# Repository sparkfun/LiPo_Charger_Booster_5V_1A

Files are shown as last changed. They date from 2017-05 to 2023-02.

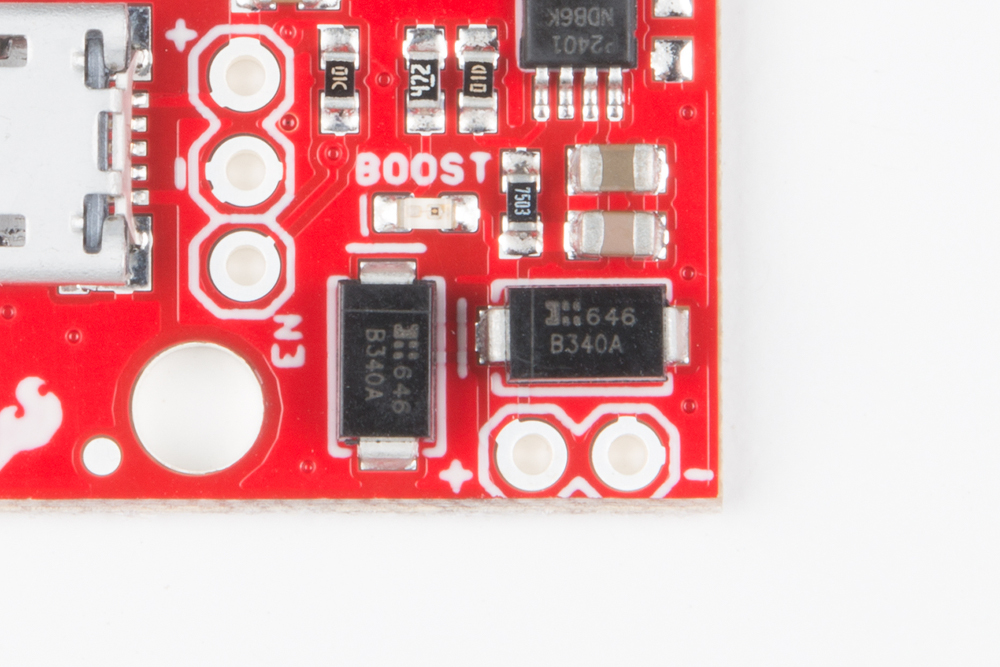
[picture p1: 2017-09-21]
Documentation/Hookup Photos/outputterms.jpg

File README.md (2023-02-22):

SparkFun LiPo Charger/Booster - 5V/1A
========================================

SparkFun LiPo Charger/Booster - 5V/1A (https://www.sparkfun.com/products/14411)

[*SparkFun LiPo Charger/Booster - 5V/1A (PRT-14411)*](https://www.sparkfun.com/products/14411)

The SparkFun 5V/1A LiPo Charger/Booster is a no-nonsense circuit for generating one amp from a Lithium Polymer battery at 5V.

Repository Contents
-------------------

* **/Documentation** - Data sheets, additional product information
* **/Hardware** - Eagle design files (.brd, .sch)
* **/Production** - Production panel files (.brd)

Documentation
--------------
* **[SparkFun Fritzing Part](https://github.com/sparkfun/Fritzing_Parts/blob/main/products/14411_sfe_LiPo_Charger_Booster-5V1A.fzpz)** - Fritzing diagrams for SparkFun products.
* **[Hookup Guide](https://learn.sparkfun.com/tutorials/sparkfun-5v1a-lipo-chargerbooster-hookup-guide)** - Basic hookup guide for the SparkFun LiPo Charger/Booster - 5V/1A.

Product Versions
----------------
* [PRT-14411](https://www.sparkfun.com/products/14411)- LiPo Charger/Booster 5V/1A

Version History
----------------
* [HW-V1.0](https://github.com/sparkfun/LiPo_Charger_Booster_5V_1A/releases/tag/HW-V1.0) 

License Information
-------------------

This product is _**open source**_! 

Please review the LICENSE.md file for license information. 

If you have any questions or concerns on licensing, please contact techsupport@sparkfun.com.

Distributed as-is; no warranty is given.

- Your friends at SparkFun.

_<COLLABORATION CREDIT>_

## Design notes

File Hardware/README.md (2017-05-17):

SparkFun <PRODUCT NAME> Design Files
=====================================

The .sch and .brd files hare are Eagle CAD schematic and PCB design files from SparkFun Electronics.
A freeware version of Eagle can be found [here](http://www.cadsoftusa.com/download-eagle/freeware/).

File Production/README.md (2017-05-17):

SparkFun <PRODUCT NAME> Production Files
=========================================

These are the production files SparkFun uses for printing PCBs.

License Information
-------------------
This product is open source! 

The hardware is released under [Creative Commons ShareAlike 4.0 International](https://creativecommons.org/licenses/by-sa/4.0/).

Please use, reuse, and modify these files as you see fit. Please maintain attribution to SparkFun Electronics and release anything derivative under the same license.

Distributed as-is; no warranty is given.

- Your friends at SparkFun.

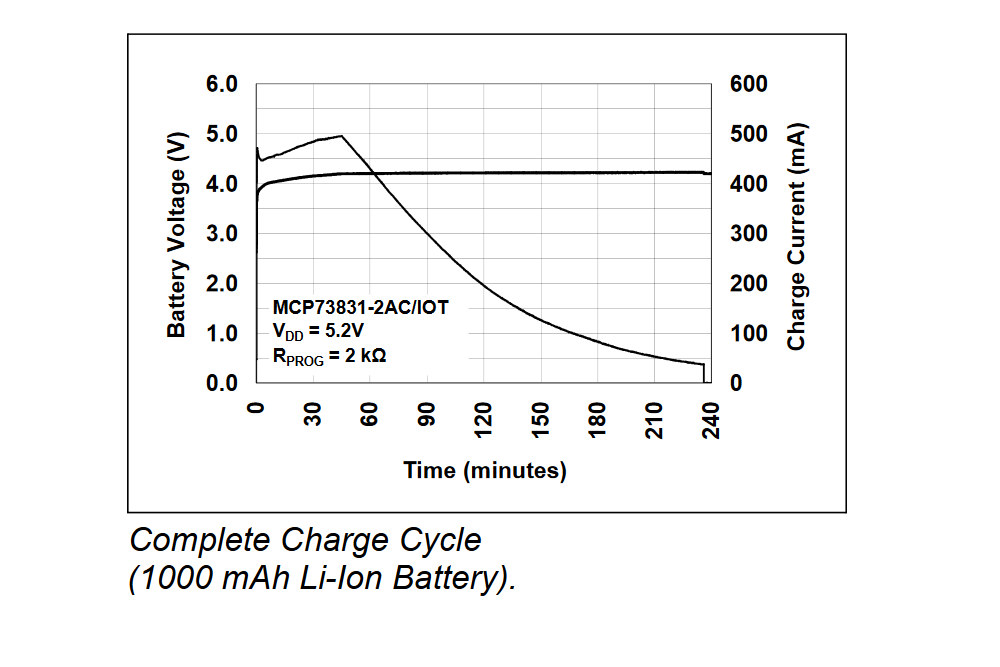
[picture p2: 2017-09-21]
Documentation/Hookup Photos/chargecycle.png

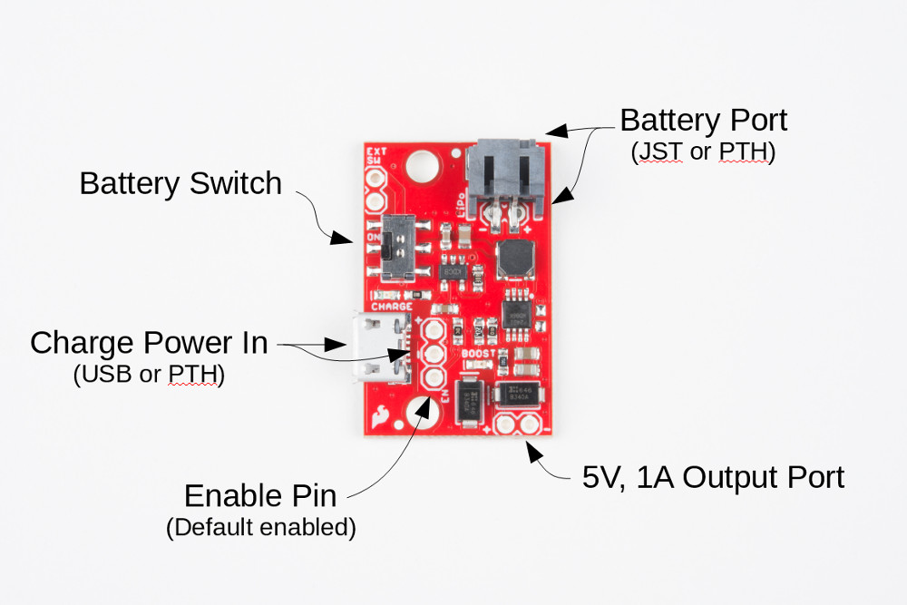
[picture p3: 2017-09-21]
Documentation/Hookup Photos/topside_notated.jpg

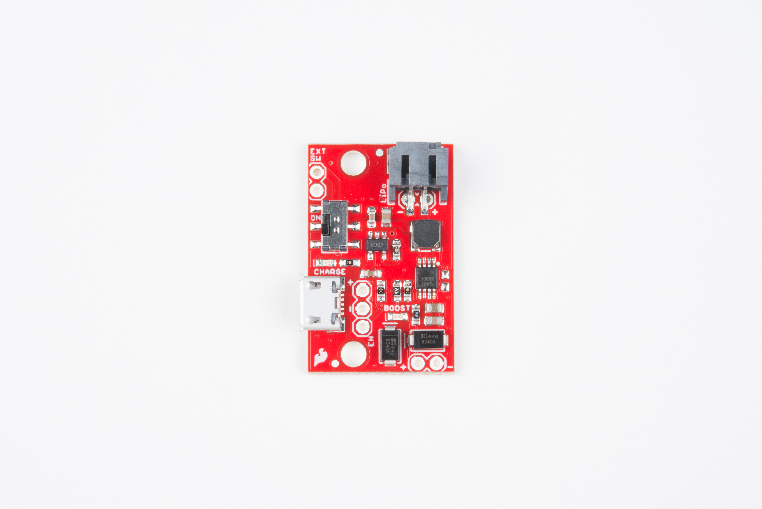
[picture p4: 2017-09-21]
Documentation/Hookup Photos/topside.jpg

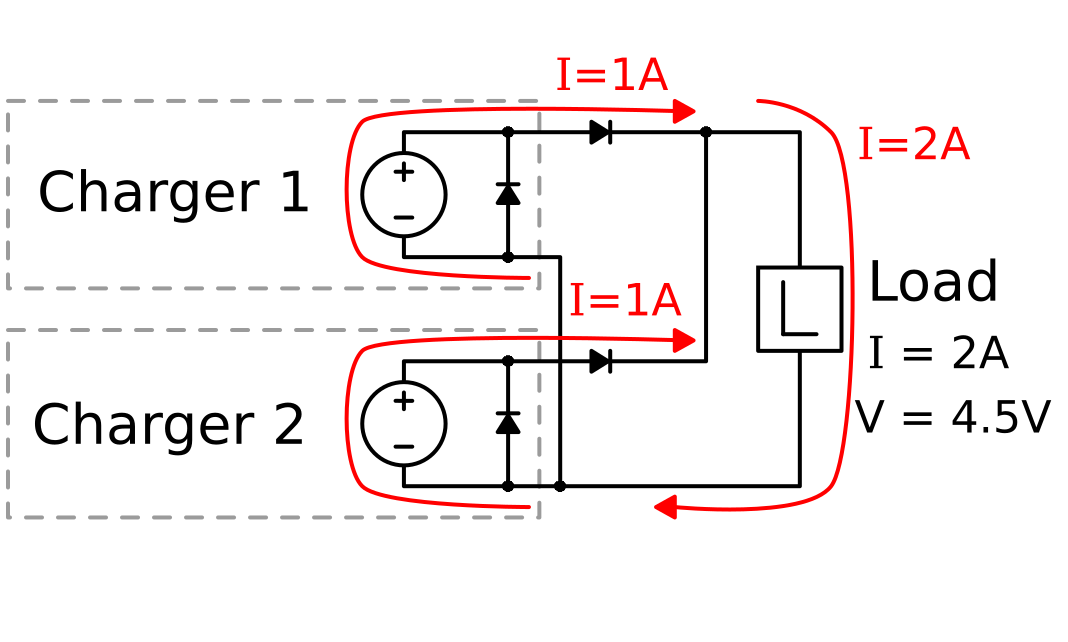
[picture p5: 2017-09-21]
Documentation/Hookup Photos/summingCurrent.png

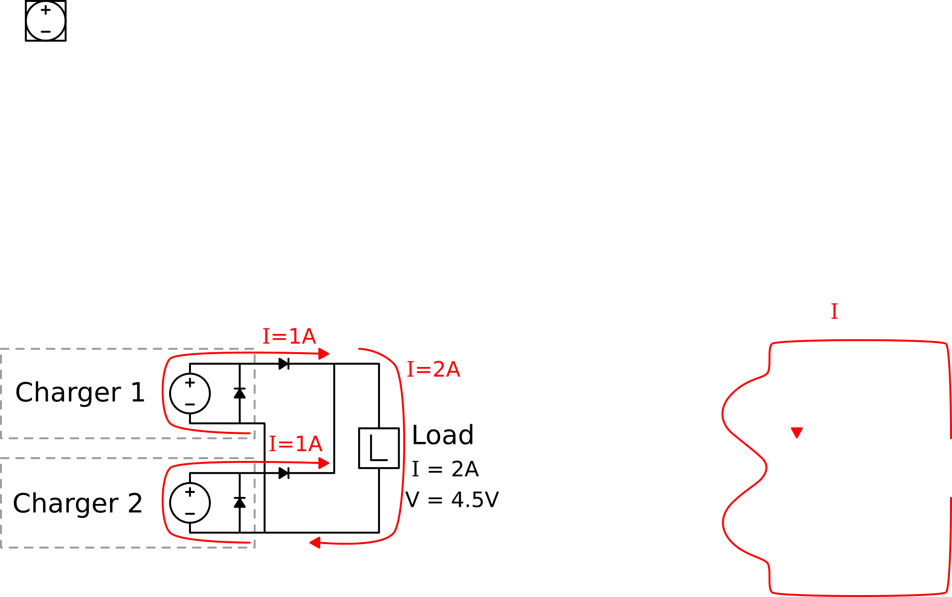
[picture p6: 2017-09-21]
Documentation/Hookup Photos/currentDrawing.png

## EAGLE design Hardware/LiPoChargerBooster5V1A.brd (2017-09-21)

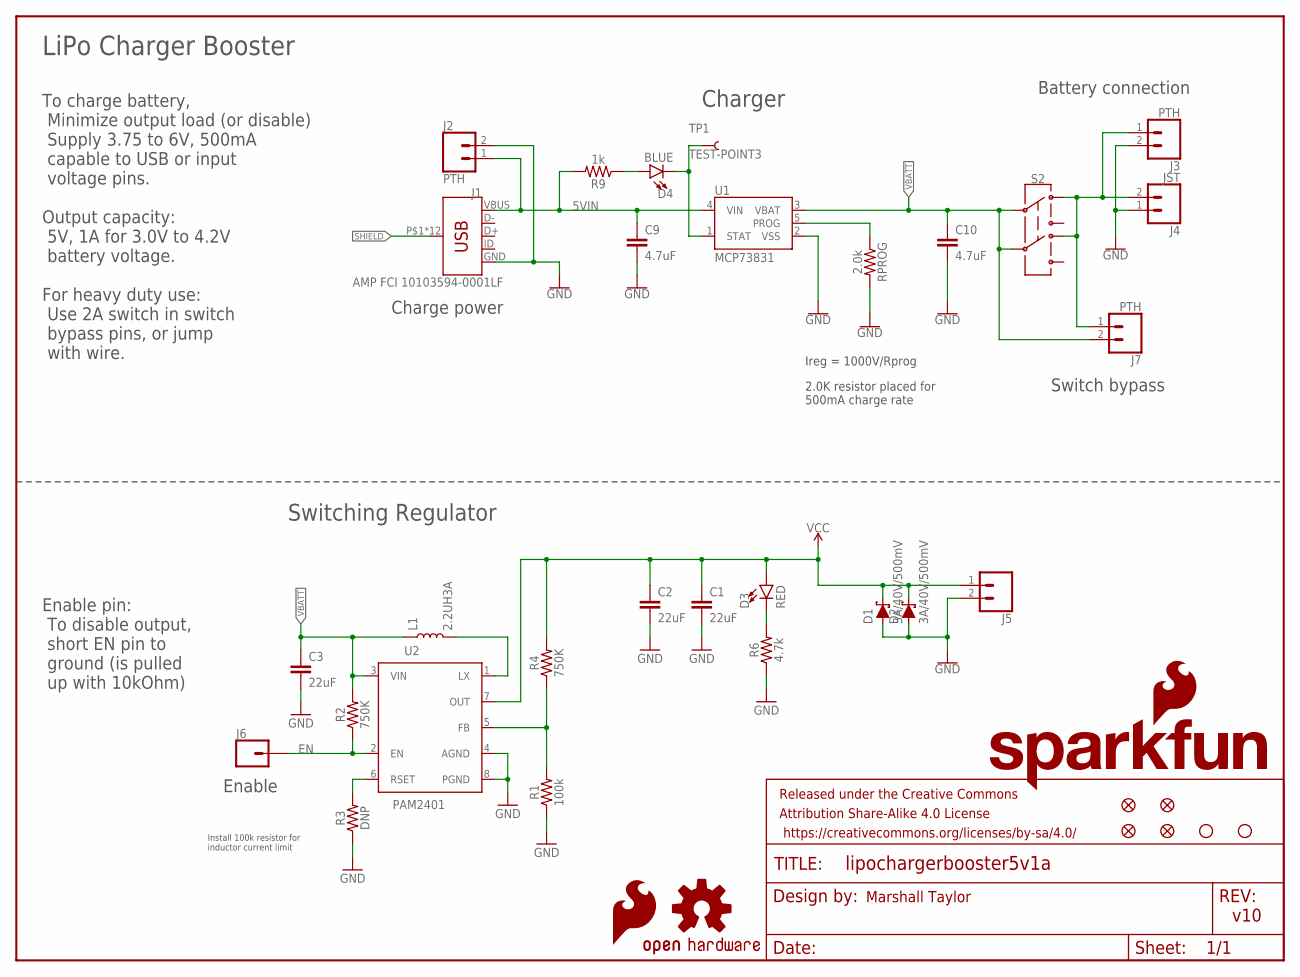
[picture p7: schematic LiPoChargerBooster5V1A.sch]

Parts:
C1, C2, C3: 22uF; 0805
C9, C10: 4.7uF; 0603
D1, D2: 3A/40V/500mV; SMA-DIODE
D3: RED; LED-0603
D4: BLUE; LED-0603
FRAME1: FRAME-LETTER; CREATIVE_COMMONS
J1: AMP FCI 10103594-0001LF; USB-MICROB-PTH
J2, J3, J7: PTH; 1X02
J4: JST; JST-2-SMD
J5: CONN_02; 1X02
J6: CONN_01; 1X01
JP1, JP2, JP4, JP16: FIDUCIAL1X2; FIDUCIAL-1X2
JP3: SFE_LOGO_NAME_FLAME.1_INCH; SFE_LOGO_NAME_FLAME_.1
JP6, JP7: STAND-OFF
L1: 2.2UH3A; INDUCTOR_4X4MM
LOGO1: SFE_LOGO_FLAME.1_INCH; SFE_LOGO_FLAME_.1
R1: 100k; 0603
R2, R4: 750K; 0603
R3: DNP; 0603
R6: 4.7k; 0603
R9: 1k; 0603
RPROG: 2.0k; 0603
S2: SWITCH-DPDT-SMD-AYZ0202; SWITCH_DPDT_SMD_AYZ0202
TP1: TEST-POINT3; PAD.03X.03
U1: MCP73831; SOT23-5
U2: PAM2401; MSOP8
U$1: OSHW-LOGOS; OSHW-LOGO-S

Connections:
5VIN: C9.1, J1.VBUS, J2.1, R9.2, U1.4 (VIN)
EN: J6.1, R2.1, U2.2 (EN)
GND: C1.2, C2.2, C3.2, C9.2, C10.2, D1.A, D2.A, J1.GND, J2.2, J3.2, J4.1 (2), J5.2, R1.1, R3.1, R6.1, RPROG.2, U1.2 (VSS), U2.4 (AGND), U2.8 (PGND)
unnamed: D3.C, R6.2
unnamed: D4.A, R9.1
unnamed: L1.P$2 (2), U2.1 (LX)
unnamed: R3.2, U2.6 (RSET)
unnamed: J3.1, J4.2 (1), J7.1, S2.1, S2.4
unnamed: RPROG.1, U1.5 (PROG)
unnamed: R1.2, R4.1, U2.5 (FB)
unnamed: D4.C, TP1.P$1, U1.1 (STAT)
SHIELD: J1.P$1 (SHIELD), J1.P$2 (SHIELD), J1.P$3 (SHIELD), J1.P$4 (SHIELD), J1.P$6 (SHIELD), J1.P$8 (SHIELD), J1.P$10 (SHIELD), J1.P$12 (SHIELD), J1.SHEILD2 (SHIELD), J1.SHIELD, J1.SHIELD3 (SHIELD), J1.SHIELD4 (SHIELD)
VBATT: C3.1, C10.1, J7.2, L1.P$1 (1), R2.2, S2.2, S2.5, U1.3 (VBAT), U2.3 (VIN)
VCC: C1.1, C2.1, D1.C, D2.C, D3.A, J5.1, R4.2, U2.7 (OUT)

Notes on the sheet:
Charger
Switching Regulator
Marshall Taylor
v10
2.0K resistor placed for 500mA charge rate
Ireg = 1000V/Rprog
To charge battery, Minimize output load (or disable) Supply 3.75 to 6V, 500mA capable to USB or input voltage pins.
Install 100k resistor for inductor current limit
LiPo Charger Booster
Output capacity: 5V, 1A for 3.0V to 4.2V battery voltage.
Enable pin: To disable output, short EN pin to ground (is pulled up with 10kOhm)
Enable
Charge power
Battery connection
Switch bypass
For heavy duty use: Use 2A switch in switch bypass pins, or jump with wire.

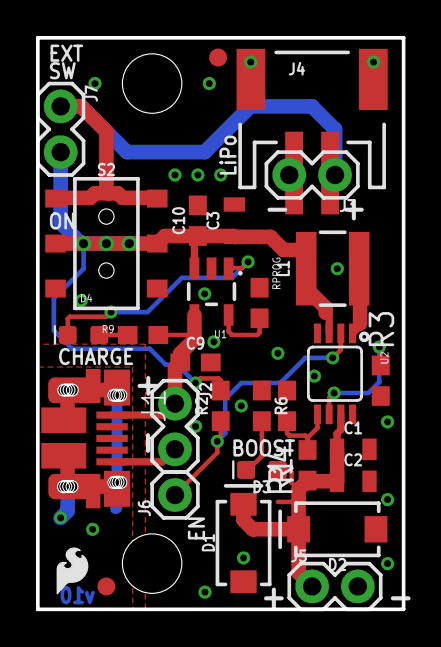
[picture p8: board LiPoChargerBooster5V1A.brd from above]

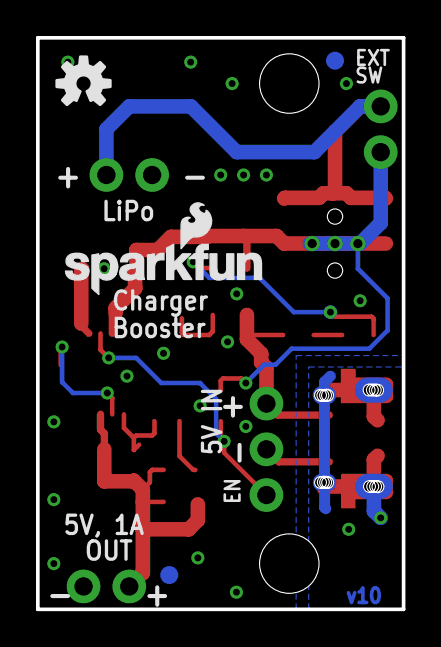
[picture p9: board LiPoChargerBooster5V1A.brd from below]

Board: 2 copper layers, 20.3 x 31.8 mm, 38 parts (5 on the bottom side), 14 nets.

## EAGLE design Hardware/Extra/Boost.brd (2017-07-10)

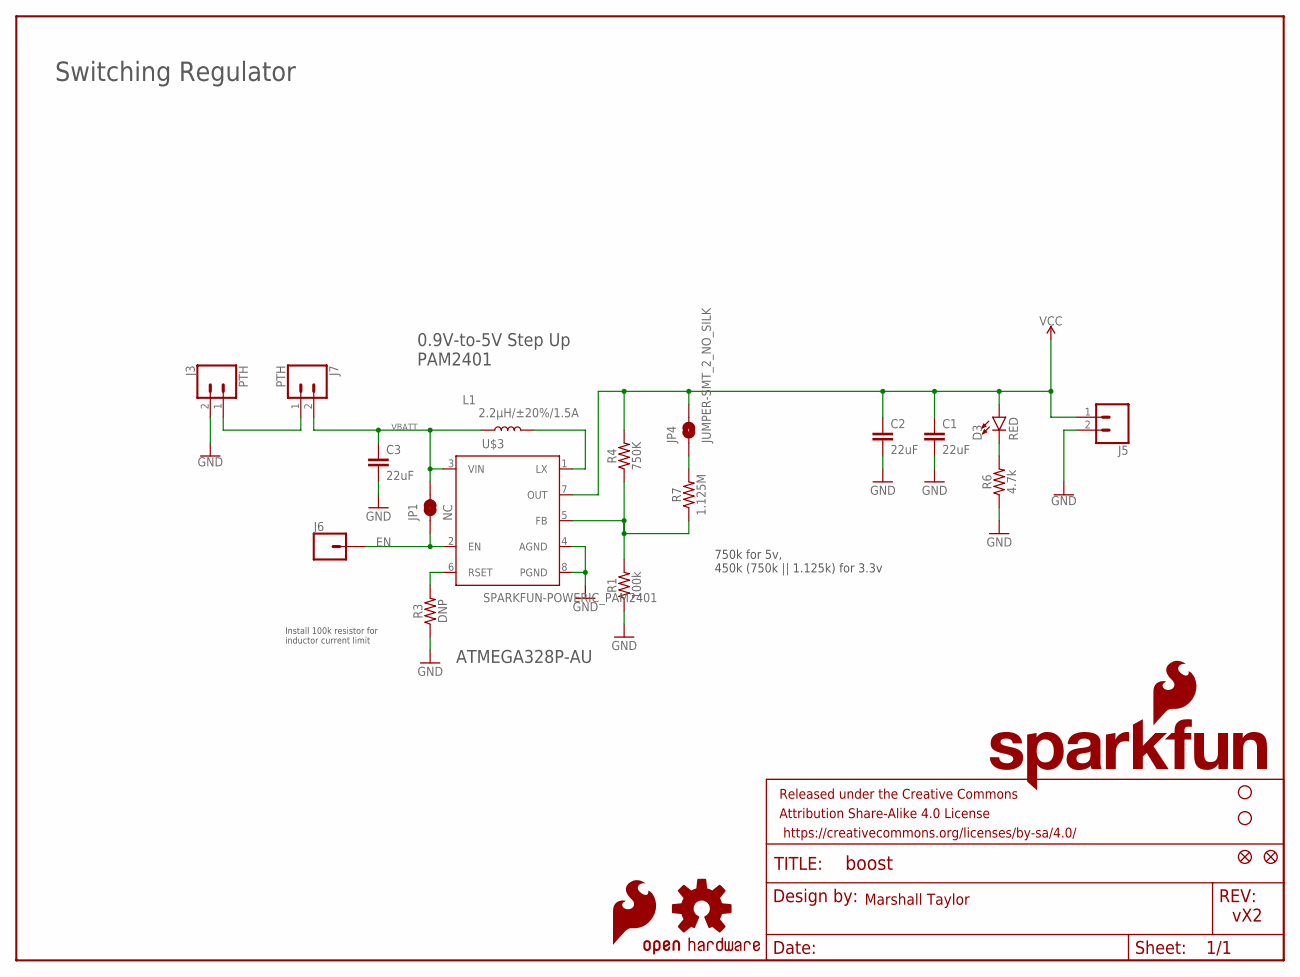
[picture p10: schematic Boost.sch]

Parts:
C1, C2, C3: 22uF; 0805
D3: RED; LED-0603
FRAME1: FRAME-LETTER; CREATIVE_COMMONS
J3, J7: PTH; 1X02_NO_SILK
J5: CONN_021X02_NO_SILK; 1X02_NO_SILK
J6: CONN_01; 1X01
JP1: NC; SMT-JUMPER_2_NC_TRACE_NO-SILK
JP2, JP16: FIDUCIAL1X2; FIDUCIAL-1X2
JP3: SFE_LOGO_NAME_FLAME.1_INCH; SFE_LOGO_NAME_FLAME_.1
JP4: JUMPER-SMT_2_NO_SILK; SMT-JUMPER_2_NO_SILK
JP6, JP7: STAND-OFF
L1: 2.2µH/±20%/1.5A; INDUCTOR_2.2UHCOPY
LOGO1: SFE_LOGO_FLAME.1_INCH; SFE_LOGO_FLAME_.1
R1: 100k; 0603
R3: DNP; 0603
R4: 750K; 0603
R6: 4.7k; 0603
R7: 1.125M; 0603
U$1: OSHW-LOGOS; OSHW-LOGO-S
U$3: SPARKFUN-POWERIC_PAM2401; SPARKFUN-POWERIC_MSOP8

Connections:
EN: J6.1, JP1.1, U$3.2 (EN)
GND: C1.2, C2.2, C3.2, J3.2, J5.2, R1.1, R3.1, R6.1, U$3.4 (AGND), U$3.8 (PGND)
unnamed: JP4.1, R7.2
unnamed: D3.C, R6.2
unnamed: L1.P$2 (2), U$3.1 (LX)
unnamed: R3.2, U$3.6 (RSET)
unnamed: J3.1, J7.1
unnamed: R1.2, R4.1, R7.1, U$3.5 (FB)
VBATT: C3.1, J7.2, JP1.2, L1.P$1 (1), U$3.3 (VIN)
VCC: C1.1, C2.1, D3.A, J5.1, JP4.2, R4.2, U$3.7 (OUT)

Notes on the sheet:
Switching Regulator
Marshall Taylor
vX2
0.9V-to-5V Step Up PAM2401
ATMEGA328P-AU
Install 100k resistor for inductor current limit
750k for 5v, 450k (750k || 1.125k) for 3.3v

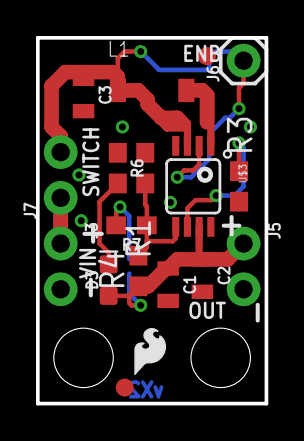
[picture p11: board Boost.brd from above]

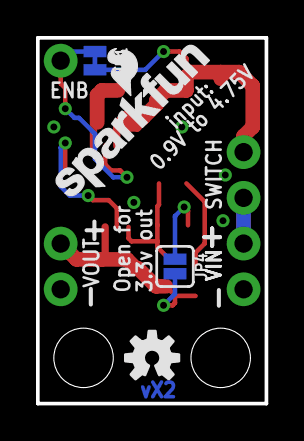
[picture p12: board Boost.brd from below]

Board: 2 copper layers, 12.7 x 20.3 mm, 25 parts (4 on the bottom side), 10 nets.

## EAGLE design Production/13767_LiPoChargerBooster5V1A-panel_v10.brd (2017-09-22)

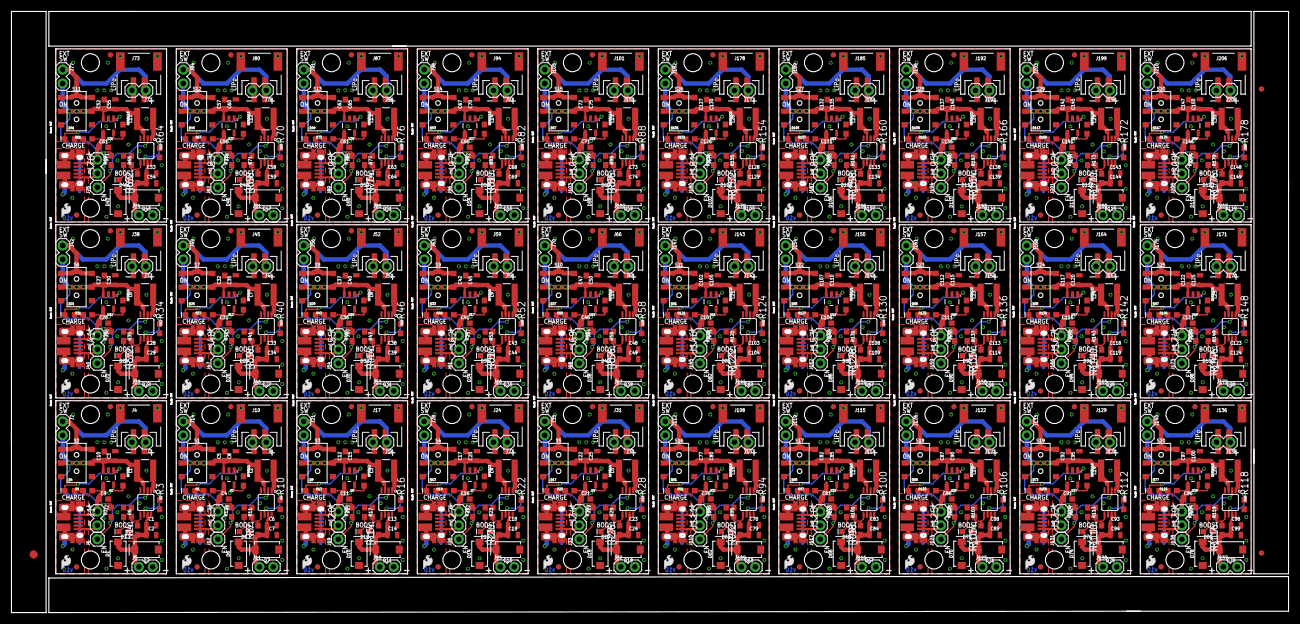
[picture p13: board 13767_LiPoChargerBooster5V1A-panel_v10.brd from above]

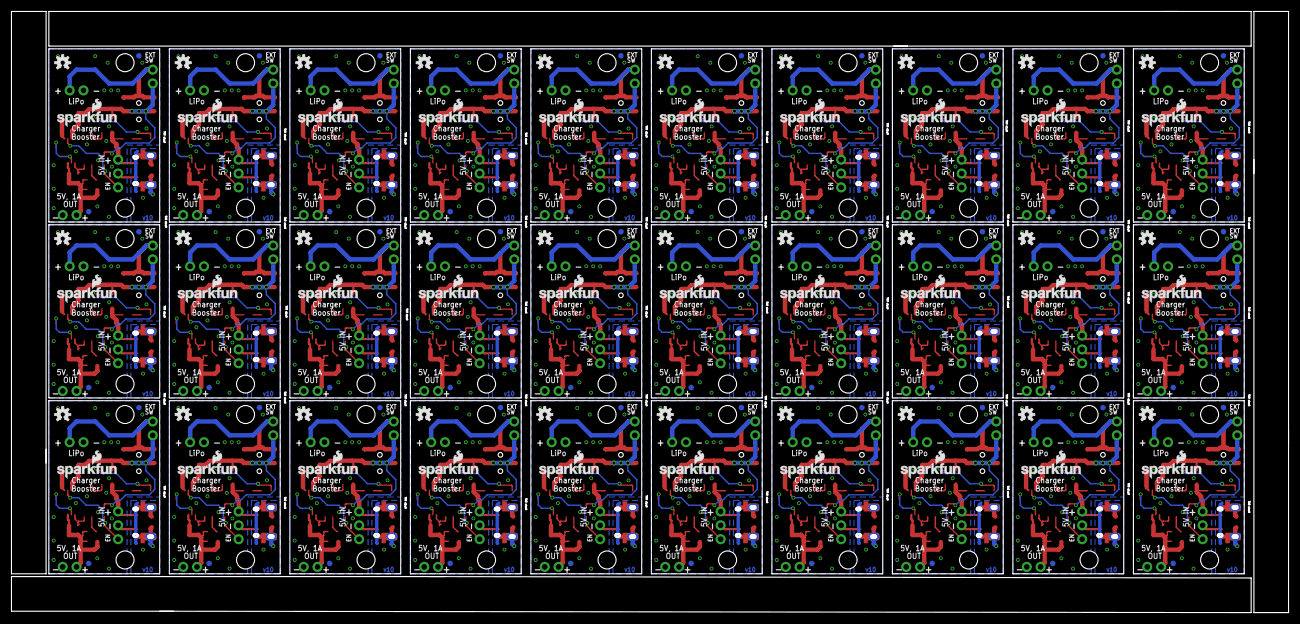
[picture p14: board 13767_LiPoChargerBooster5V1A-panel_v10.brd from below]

Board: 2 copper layers, 234.2 x 110.2 mm, 1113 parts (150 on the bottom side), 420 nets.

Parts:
C1, C2, C3, C6, C7, C8, C13, C14, C15, C18, C19, C20, C23, C24, C25, C28, C29, C30, C33, C34, C35, C38, C39, C40, C43, C44, C45, C48, C49, C50, C53, C54, C55, C58, C59, C60, C63, C64, C65, C68, C69, C70, C73, C74, C75, C78, C79, C80, C83, C84, C85, C88, C89, C90, C93, C94, C95, C98, C99, C100, C103, C104, C105, C108, C109, C110, C113, C114, C115, C118, C119, C120, C123, C124, C125, C128, C129, C130, C133, C134, C135, C138, C139, C140, C143, C144, C145, C148, C149, C150: 22uF; 0805
C4, C5, C9, C10, C11, C12, C16, C17, C21, C22, C26, C27, C31, C32, C36, C37, C41, C42, C46, C47, C51, C52, C56, C57, C61, C62, C66, C67, C71, C72, C76, C77, C81, C82, C86, C87, C91, C92, C96, C97, C101, C102, C106, C107, C111, C112, C116, C117, C121, C122, C126, C127, C131, C132, C136, C137, C141, C142, C146, C147: 4.7uF; 0603
D1, D2, D6, D7, D10, D11, D14, D15, D18, D19, D22, D23, D26, D27, D30, D31, D34, D35, D38, D39, D42, D43, D46, D47, D50, D51, D54, D55, D58, D59, D62, D63, D66, D67, D70, D71, D74, D75, D78, D79, D82, D83, D86, D87, D90, D91, D94, D95, D98, D99, D102, D103, D106, D107, D110, D111, D114, D115, D118, D119: 3A/40V/500mV; SMA-DIODE
D3, D8, D12, D16, D20, D24, D28, D32, D36, D40, D44, D48, D52, D56, D60, D64, D68, D72, D76, D80, D84, D88, D92, D96, D100, D104, D108, D112, D116, D120: RED; LED-0603
D4, D5, D9, D13, D17, D21, D25, D29, D33, D37, D41, D45, D49, D53, D57, D61, D65, D69, D73, D77, D81, D85, D89, D93, D97, D101, D105, D109, D113, D117: BLUE; LED-0603
E$1: FIDUCIAL-1.5X3
E$5, E$6: FIDUCIAL-1X2
J1, J13, J20, J27, J34, J41, J48, J55, J62, J69, J76, J83, J90, J97, J104, J111, J118, J125, J132, J139, J146, J153, J160, J167, J174, J181, J188, J195, J202, J209: AMP FCI 10103594-0001LF; USB-MICROB-PTH
J2, J3, J7, J8, J9, J14, J15, J16, J21, J22, J23, J28, J29, J30, J35, J36, J37, J42, J43, J44, J49, J50, J51, J56, J57, J58, J63, J64, J65, J70, J71, J72, J77, J78, J79, J84, J85, J86, J91, J92, J93, J98, J99, J100, J105, J106, J107, J112, J113, J114, J119, J120, J121, J126, J127, J128, J133, J134, J135, J140, J141, J142, J147, J148, J149, J154, J155, J156, J161, J162, J163, J168, J169, J170, J175, J176, J177, J182, J183, J184, J189, J190, J191, J196, J197, J198, J203, J204, J205, J210: PTH; 1X02
J4, J10, J17, J24, J31, J38, J45, J52, J59, J66, J73, J80, J87, J94, J101, J108, J115, J122, J129, J136, J143, J150, J157, J164, J171, J178, J185, J192, J199, J206: JST; JST-2-SMD
J5, J11, J18, J25, J32, J39, J46, J53, J60, J67, J74, J81, J88, J95, J102, J109, J116, J123, J130, J137, J144, J151, J158, J165, J172, J179, J186, J193, J200, J207: 1X02
J6, J12, J19, J26, J33, J40, J47, J54, J61, J68, J75, J82, J89, J96, J103, J110, J117, J124, J131, J138, J145, J152, J159, J166, J173, J180, J187, J194, J201, J208: 1X01
JP1, JP2, JP4, JP10, JP11, JP12, JP13, JP16, JP18, JP19, JP20, JP21, JP25, JP26, JP27, JP28, JP32, JP33, JP34, JP35, JP39, JP40, JP41, JP42, JP46, JP47, JP48, JP49, JP53, JP54, JP55, JP56, JP60, JP61, JP62, JP63, JP67, JP68, JP69, JP70, JP74, JP75, JP76, JP77, JP81, JP82, JP83, JP84, JP88, JP89, JP90, JP91, JP95, JP96, JP97, JP98, JP102, JP103, JP104, JP105, JP109, JP110, JP111, JP112, JP116, JP117, JP118, JP119, JP123, JP124, JP125, JP126, JP130, JP131, JP132, JP133, JP137, JP138, JP139, JP140, JP144, JP145, JP146, JP147, JP151, JP152, JP153, JP154, JP158, JP159, JP160, JP161, JP165, JP166, JP167, JP168, JP172, JP173, JP174, JP175, JP179, JP180, JP181, JP182, JP186, JP187, JP188, JP189, JP193, JP194, JP195, JP196, JP200, JP201, JP202, JP203, JP207, JP208, JP209, JP210: FIDUCIAL1X2; FIDUCIAL-1X2
JP3, JP5, JP14, JP22, JP29, JP36, JP43, JP50, JP57, JP64, JP71, JP78, JP85, JP92, JP99, JP106, JP113, JP120, JP127, JP134, JP141, JP148, JP155, JP162, JP169, JP176, JP183, JP190, JP197, JP204: SFE_LOGO_NAME_FLAME.1_INCH; SFE_LOGO_NAME_FLAME_.1
JP6, JP7, JP8, JP9, JP15, JP17, JP23, JP24, JP30, JP31, JP37, JP38, JP44, JP45, JP51, JP52, JP58, JP59, JP65, JP66, JP72, JP73, JP79, JP80, JP86, JP87, JP93, JP94, JP100, JP101, JP107, JP108, JP114, JP115, JP121, JP122, JP128, JP129, JP135, JP136, JP142, JP143, JP149, JP150, JP156, JP157, JP163, JP164, JP170, JP171, JP177, JP178, JP184, JP185, JP191, JP192, JP198, JP199, JP205, JP206: STAND-OFF
L1, L2, L3, L4, L5, L6, L7, L8, L9, L10, L11, L12, L13, L14, L15, L16, L17, L18, L19, L20, L21, L22, L23, L24, L25, L26, L27, L28, L29, L30: 2.2UH3A; INDUCTOR_4X4MM
LOGO1, LOGO2, LOGO3, LOGO4, LOGO5, LOGO6, LOGO7, LOGO8, LOGO9, LOGO10, LOGO11, LOGO12, LOGO13, LOGO14, LOGO15, LOGO16, LOGO17, LOGO18, LOGO19, LOGO20, LOGO21, LOGO22, LOGO23, LOGO24, LOGO25, LOGO26, LOGO27, LOGO28, LOGO29, LOGO30: SFE_LOGO_FLAME.1_INCH; SFE_LOGO_FLAME_.1
R1, R8, R15, R21, R27, R33, R39, R45, R51, R57, R63, R69, R75, R81, R87, R93, R99, R105, R111, R117, R123, R129, R135, R141, R147, R153, R159, R165, R171, R177: 100k; 0603
R2, R12, R18, R24, R30, R36, R42, R48, R54, R60, R66, R72, R78, R84, R90, R96, R102, R108, R114, R120, R126, R132, R138, R144, R150, R156, R162, R168, R174, R180: 10k; 0603
R3, R10, R16, R22, R28, R34, R40, R46, R52, R58, R64, R70, R76, R82, R88, R94, R100, R106, R112, R118, R124, R130, R136, R142, R148, R154, R160, R166, R172, R178: DNP; 0603
R4, R7, R14, R20, R26, R32, R38, R44, R50, R56, R62, R68, R74, R80, R86, R92, R98, R104, R110, R116, R122, R128, R134, R140, R146, R152, R158, R164, R170, R176: 750K; 0603
R5, R9, R13, R19, R25, R31, R37, R43, R49, R55, R61, R67, R73, R79, R85, R91, R97, R103, R109, R115, R121, R127, R133, R139, R145, R151, R157, R163, R169, R175: 1k; 0603
R6, R11, R17, R23, R29, R35, R41, R47, R53, R59, R65, R71, R77, R83, R89, R95, R101, R107, R113, R119, R125, R131, R137, R143, R149, R155, R161, R167, R173, R179: 4.7k; 0603
RPROG, RPROG1, RPROG2, RPROG3, RPROG4, RPROG5, RPROG6, RPROG7, RPROG8, RPROG9, RPROG10, RPROG11, RPROG12, RPROG13, RPROG14, RPROG15, RPROG16, RPROG17, RPROG18, RPROG19, RPROG20, RPROG21, RPROG22, RPROG23, RPROG24, RPROG25, RPROG26, RPROG27, RPROG28, RPROG29: 2.0k; 0603
S1, S2, S3, S4, S5, S6, S7, S8, S9, S10, S11, S12, S13, S14, S15, S16, S17, S18, S19, S20, S21, S22, S23, S24, S25, S26, S27, S28, S29, S30: SWITCH_DPDT_SMD_AYZ0202
TP1, TP2, TP3, TP4, TP5, TP6, TP7, TP8, TP9, TP10, TP11, TP12, TP13, TP14, TP15, TP16, TP17, TP18, TP19, TP20, TP21, TP22, TP23, TP24, TP25, TP26, TP27, TP28, TP29, TP30: TEST-POINT3; PAD.03X.03
U1, U3, U5, U7, U9, U11, U13, U15, U17, U19, U21, U23, U25, U27, U29, U31, U33, U35, U37, U39, U41, U43, U45, U47, U49, U51, U53, U55, U57, U59: MCP73831; SOT23-5
U2, U4, U6, U8, U10, U12, U14, U16, U18, U20, U22, U24, U26, U28, U30, U32, U34, U36, U38, U40, U42, U44, U46, U48, U50, U52, U54, U56, U58, U60: PAM2401; MSOP8
U$1, U$2, U$3, U$4, U$5, U$6, U$7, U$8, U$9, U$10, U$11, U$12, U$13, U$14, U$15, U$16, U$17, U$18, U$19, U$20, U$21, U$22, U$23, U$24, U$25, U$26, U$27, U$28, U$29, U$30: OSHW-LOGOS; OSHW-LOGO-S

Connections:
5VIN: C9.1, J1.VBUS, J2.1, R9.2, U1.4
5VIN1: C4.1, J8.1, J13.VBUS, R5.2, U3.4
5VIN2: C11.1, J15.1, J20.VBUS, R13.2, U5.4
5VIN3: C16.1, J22.1, J27.VBUS, R19.2, U7.4
5VIN4: C21.1, J29.1, J34.VBUS, R25.2, U9.4
5VIN5: C26.1, J36.1, J41.VBUS, R31.2, U11.4
5VIN6: C31.1, J43.1, J48.VBUS, R37.2, U13.4
5VIN7: C36.1, J50.1, J55.VBUS, R43.2, U15.4
5VIN8: C41.1, J57.1, J62.VBUS, R49.2, U17.4
5VIN9: C46.1, J64.1, J69.VBUS, R55.2, U19.4
5VIN10: C51.1, J71.1, J76.VBUS, R61.2, U21.4
5VIN11: C56.1, J78.1, J83.VBUS, R67.2, U23.4
5VIN12: C61.1, J85.1, J90.VBUS, R73.2, U25.4
5VIN13: C66.1, J92.1, J97.VBUS, R79.2, U27.4
5VIN14: C71.1, J99.1, J104.VBUS, R85.2, U29.4
5VIN15: C76.1, J106.1, J111.VBUS, R91.2, U31.4
5VIN16: C81.1, J113.1, J118.VBUS, R97.2, U33.4
5VIN17: C86.1, J120.1, J125.VBUS, R103.2, U35.4
5VIN18: C91.1, J127.1, J132.VBUS, R109.2, U37.4
5VIN19: C96.1, J134.1, J139.VBUS, R115.2, U39.4
5VIN20: C101.1, J141.1, J146.VBUS, R121.2, U41.4
5VIN21: C106.1, J148.1, J153.VBUS, R127.2, U43.4
5VIN22: C111.1, J155.1, J160.VBUS, R133.2, U45.4
5VIN23: C116.1, J162.1, J167.VBUS, R139.2, U47.4
5VIN24: C121.1, J169.1, J174.VBUS, R145.2, U49.4
5VIN25: C126.1, J176.1, J181.VBUS, R151.2, U51.4
5VIN26: C131.1, J183.1, J188.VBUS, R157.2, U53.4
5VIN27: C136.1, J190.1, J195.VBUS, R163.2, U55.4
5VIN28: C141.1, J197.1, J202.VBUS, R169.2, U57.4
5VIN29: C146.1, J204.1, J209.VBUS, R175.2, U59.4
EN: J6.1, R2.1, U2.2
EN1: J12.1, R12.1, U4.2
EN2: J19.1, R18.1, U6.2
EN3: J26.1, R24.1, U8.2
EN4: J33.1, R30.1, U10.2
EN5: J40.1, R36.1, U12.2
EN6: J47.1, R42.1, U14.2
EN7: J54.1, R48.1, U16.2
EN8: J61.1, R54.1, U18.2
EN9: J68.1, R60.1, U20.2
EN10: J75.1, R66.1, U22.2
EN11: J82.1, R72.1, U24.2
EN12: J89.1, R78.1, U26.2
EN13: J96.1, R84.1, U28.2
EN14: J103.1, R90.1, U30.2
EN15: J110.1, R96.1, U32.2
EN16: J117.1, R102.1, U34.2
EN17: J124.1, R108.1, U36.2
EN18: J131.1, R114.1, U38.2
EN19: J138.1, R120.1, U40.2
EN20: J145.1, R126.1, U42.2
EN21: J152.1, R132.1, U44.2
EN22: J159.1, R138.1, U46.2
EN23: J166.1, R144.1, U48.2
EN24: J173.1, R150.1, U50.2
EN25: J180.1, R156.1, U52.2
EN26: J187.1, R162.1, U54.2
EN27: J194.1, R168.1, U56.2
EN28: J201.1, R174.1, U58.2
EN29: J208.1, R180.1, U60.2
GND: C1.2, C2.2, C3.2, C9.2, C10.2, D1.A, D2.A, J1.GND, J2.2, J3.2, J4.1, J5.2, R1.1, R3.1, R6.1, RPROG.2, U1.2, U2.4, U2.8
GND1: C4.2, C5.2, C6.2, C7.2, C8.2, D6.A, D7.A, J8.2, J9.2, J10.1, J11.2, J13.GND, R8.1, R10.1, R11.1, RPROG1.2, U3.2, U4.4, U4.8
GND2: C11.2, C12.2, C13.2, C14.2, C15.2, D10.A, D11.A, J15.2, J16.2, J17.1, J18.2, J20.GND, R15.1, R16.1, R17.1, RPROG2.2, U5.2, U6.4, U6.8
GND3: C16.2, C17.2, C18.2, C19.2, C20.2, D14.A, D15.A, J22.2, J23.2, J24.1, J25.2, J27.GND, R21.1, R22.1, R23.1, RPROG3.2, U7.2, U8.4, U8.8
GND4: C21.2, C22.2, C23.2, C24.2, C25.2, D18.A, D19.A, J29.2, J30.2, J31.1, J32.2, J34.GND, R27.1, R28.1, R29.1, RPROG4.2, U9.2, U10.4, U10.8
GND5: C26.2, C27.2, C28.2, C29.2, C30.2, D22.A, D23.A, J36.2, J37.2, J38.1, J39.2, J41.GND, R33.1, R34.1, R35.1, RPROG5.2, U11.2, U12.4, U12.8
GND6: C31.2, C32.2, C33.2, C34.2, C35.2, D26.A, D27.A, J43.2, J44.2, J45.1, J46.2, J48.GND, R39.1, R40.1, R41.1, RPROG6.2, U13.2, U14.4, U14.8
GND7: C36.2, C37.2, C38.2, C39.2, C40.2, D30.A, D31.A, J50.2, J51.2, J52.1, J53.2, J55.GND, R45.1, R46.1, R47.1, RPROG7.2, U15.2, U16.4, U16.8
GND8: C41.2, C42.2, C43.2, C44.2, C45.2, D34.A, D35.A, J57.2, J58.2, J59.1, J60.2, J62.GND, R51.1, R52.1, R53.1, RPROG8.2, U17.2, U18.4, U18.8
GND9: C46.2, C47.2, C48.2, C49.2, C50.2, D38.A, D39.A, J64.2, J65.2, J66.1, J67.2, J69.GND, R57.1, R58.1, R59.1, RPROG9.2, U19.2, U20.4, U20.8
GND10: C51.2, C52.2, C53.2, C54.2, C55.2, D42.A, D43.A, J71.2, J72.2, J73.1, J74.2, J76.GND, R63.1, R64.1, R65.1, RPROG10.2, U21.2, U22.4, U22.8
GND11: C56.2, C57.2, C58.2, C59.2, C60.2, D46.A, D47.A, J78.2, J79.2, J80.1, J81.2, J83.GND, R69.1, R70.1, R71.1, RPROG11.2, U23.2, U24.4, U24.8
GND12: C61.2, C62.2, C63.2, C64.2, C65.2, D50.A, D51.A, J85.2, J86.2, J87.1, J88.2, J90.GND, R75.1, R76.1, R77.1, RPROG12.2, U25.2, U26.4, U26.8
GND13: C66.2, C67.2, C68.2, C69.2, C70.2, D54.A, D55.A, J92.2, J93.2, J94.1, J95.2, J97.GND, R81.1, R82.1, R83.1, RPROG13.2, U27.2, U28.4, U28.8
GND14: C71.2, C72.2, C73.2, C74.2, C75.2, D58.A, D59.A, J99.2, J100.2, J101.1, J102.2, J104.GND, R87.1, R88.1, R89.1, RPROG14.2, U29.2, U30.4, U30.8
GND15: C76.2, C77.2, C78.2, C79.2, C80.2, D62.A, D63.A, J106.2, J107.2, J108.1, J109.2, J111.GND, R93.1, R94.1, R95.1, RPROG15.2, U31.2, U32.4, U32.8
GND16: C81.2, C82.2, C83.2, C84.2, C85.2, D66.A, D67.A, J113.2, J114.2, J115.1, J116.2, J118.GND, R99.1, R100.1, R101.1, RPROG16.2, U33.2, U34.4, U34.8
GND17: C86.2, C87.2, C88.2, C89.2, C90.2, D70.A, D71.A, J120.2, J121.2, J122.1, J123.2, J125.GND, R105.1, R106.1, R107.1, RPROG17.2, U35.2, U36.4, U36.8
GND18: C91.2, C92.2, C93.2, C94.2, C95.2, D74.A, D75.A, J127.2, J128.2, J129.1, J130.2, J132.GND, R111.1, R112.1, R113.1, RPROG18.2, U37.2, U38.4, U38.8
GND19: C96.2, C97.2, C98.2, C99.2, C100.2, D78.A, D79.A, J134.2, J135.2, J136.1, J137.2, J139.GND, R117.1, R118.1, R119.1, RPROG19.2, U39.2, U40.4, U40.8
GND20: C101.2, C102.2, C103.2, C104.2, C105.2, D82.A, D83.A, J141.2, J142.2, J143.1, J144.2, J146.GND, R123.1, R124.1, R125.1, RPROG20.2, U41.2, U42.4, U42.8
GND21: C106.2, C107.2, C108.2, C109.2, C110.2, D86.A, D87.A, J148.2, J149.2, J150.1, J151.2, J153.GND, R129.1, R130.1, R131.1, RPROG21.2, U43.2, U44.4, U44.8
GND22: C111.2, C112.2, C113.2, C114.2, C115.2, D90.A, D91.A, J155.2, J156.2, J157.1, J158.2, J160.GND, R135.1, R136.1, R137.1, RPROG22.2, U45.2, U46.4, U46.8
GND23: C116.2, C117.2, C118.2, C119.2, C120.2, D94.A, D95.A, J162.2, J163.2, J164.1, J165.2, J167.GND, R141.1, R142.1, R143.1, RPROG23.2, U47.2, U48.4, U48.8
GND24: C121.2, C122.2, C123.2, C124.2, C125.2, D98.A, D99.A, J169.2, J170.2, J171.1, J172.2, J174.GND, R147.1, R148.1, R149.1, RPROG24.2, U49.2, U50.4, U50.8
GND25: C126.2, C127.2, C128.2, C129.2, C130.2, D102.A, D103.A, J176.2, J177.2, J178.1, J179.2, J181.GND, R153.1, R154.1, R155.1, RPROG25.2, U51.2, U52.4, U52.8
GND26: C131.2, C132.2, C133.2, C134.2, C135.2, D106.A, D107.A, J183.2, J184.2, J185.1, J186.2, J188.GND, R159.1, R160.1, R161.1, RPROG26.2, U53.2, U54.4, U54.8
GND27: C136.2, C137.2, C138.2, C139.2, C140.2, D110.A, D111.A, J190.2, J191.2, J192.1, J193.2, J195.GND, R165.1, R166.1, R167.1, RPROG27.2, U55.2, U56.4, U56.8
GND28: C141.2, C142.2, C143.2, C144.2, C145.2, D114.A, D115.A, J197.2, J198.2, J199.1, J200.2, J202.GND, R171.1, R172.1, R173.1, RPROG28.2, U57.2, U58.4, U58.8
GND29: C146.2, C147.2, C148.2, C149.2, C150.2, D118.A, D119.A, J204.2, J205.2, J206.1, J207.2, J209.GND, R177.1, R178.1, R179.1, RPROG29.2, U59.2, U60.4, U60.8
unnamed: RPROG1.1, U3.5
unnamed: D3.C, R6.2
unnamed: D4.A, R9.1
unnamed: L1.P$2, U2.1
unnamed: R3.2, U2.6
unnamed: D5.C, TP2.P$1, U3.1
unnamed: J3.1, J4.2, J7.1, S2.1, S2.4
unnamed: L2.P$2, U4.1
unnamed: RPROG.1, U1.5
unnamed: R1.2, R4.1, U2.5
unnamed: R7.1, R8.2, U4.5
unnamed: D4.C, TP1.P$1, U1.1
unnamed: R10.2, U4.6
unnamed: J9.1, J10.2, J14.1, S1.1, S1.4
unnamed: D8.C, R11.2
unnamed: D5.A, R5.1
unnamed: RPROG2.1, U5.5
unnamed: D9.C, TP3.P$1, U5.1
unnamed: L3.P$2, U6.1
unnamed: R14.1, R15.2, U6.5
unnamed: R16.2, U6.6
unnamed: J16.1, J17.2, J21.1, S3.1, S3.4
unnamed: D12.C, R17.2
unnamed: D9.A, R13.1
unnamed: RPROG3.1, U7.5
unnamed: D13.C, TP4.P$1, U7.1
unnamed: L4.P$2, U8.1
unnamed: R20.1, R21.2, U8.5
unnamed: R22.2, U8.6
unnamed: J23.1, J24.2, J28.1, S4.1, S4.4
unnamed: D16.C, R23.2
unnamed: D13.A, R19.1
unnamed: RPROG4.1, U9.5
unnamed: D17.C, TP5.P$1, U9.1
unnamed: L5.P$2, U10.1
unnamed: R26.1, R27.2, U10.5
unnamed: R28.2, U10.6
unnamed: J30.1, J31.2, J35.1, S5.1, S5.4
unnamed: D20.C, R29.2
unnamed: D17.A, R25.1
unnamed: RPROG5.1, U11.5
unnamed: D21.C, TP6.P$1, U11.1
unnamed: L6.P$2, U12.1
unnamed: R32.1, R33.2, U12.5
unnamed: R34.2, U12.6
unnamed: J37.1, J38.2, J42.1, S6.1, S6.4
unnamed: D24.C, R35.2
unnamed: D21.A, R31.1
unnamed: RPROG6.1, U13.5
unnamed: D25.C, TP7.P$1, U13.1
unnamed: L7.P$2, U14.1
unnamed: R38.1, R39.2, U14.5
unnamed: R40.2, U14.6
unnamed: J44.1, J45.2, J49.1, S7.1, S7.4
unnamed: D28.C, R41.2
unnamed: D25.A, R37.1
unnamed: RPROG7.1, U15.5
unnamed: D29.C, TP8.P$1, U15.1
unnamed: L8.P$2, U16.1
unnamed: R44.1, R45.2, U16.5
unnamed: R46.2, U16.6
unnamed: J51.1, J52.2, J56.1, S8.1, S8.4
unnamed: D32.C, R47.2
unnamed: D29.A, R43.1
unnamed: RPROG8.1, U17.5
unnamed: D33.C, TP9.P$1, U17.1
unnamed: L9.P$2, U18.1
unnamed: R50.1, R51.2, U18.5
unnamed: R52.2, U18.6
unnamed: J58.1, J59.2, J63.1, S9.1, S9.4
unnamed: D36.C, R53.2
unnamed: D33.A, R49.1
unnamed: RPROG9.1, U19.5
unnamed: D37.C, TP10.P$1, U19.1
unnamed: L10.P$2, U20.1
unnamed: R56.1, R57.2, U20.5
unnamed: R58.2, U20.6
unnamed: J65.1, J66.2, J70.1, S10.1, S10.4
unnamed: D40.C, R59.2
unnamed: D37.A, R55.1
unnamed: RPROG10.1, U21.5
unnamed: D41.C, TP11.P$1, U21.1
unnamed: L11.P$2, U22.1
unnamed: R62.1, R63.2, U22.5
unnamed: R64.2, U22.6
unnamed: J72.1, J73.2, J77.1, S11.1, S11.4
unnamed: D44.C, R65.2
unnamed: D41.A, R61.1
unnamed: RPROG11.1, U23.5
unnamed: D45.C, TP12.P$1, U23.1
unnamed: L12.P$2, U24.1
unnamed: R68.1, R69.2, U24.5
unnamed: R70.2, U24.6
unnamed: J79.1, J80.2, J84.1, S12.1, S12.4
unnamed: D48.C, R71.2
unnamed: D45.A, R67.1
unnamed: RPROG12.1, U25.5
unnamed: D49.C, TP13.P$1, U25.1
unnamed: L13.P$2, U26.1
unnamed: R74.1, R75.2, U26.5
unnamed: R76.2, U26.6
unnamed: J86.1, J87.2, J91.1, S13.1, S13.4
unnamed: D52.C, R77.2
unnamed: D49.A, R73.1
unnamed: RPROG13.1, U27.5
unnamed: D53.C, TP14.P$1, U27.1
unnamed: L14.P$2, U28.1
unnamed: R80.1, R81.2, U28.5
unnamed: R82.2, U28.6
unnamed: J93.1, J94.2, J98.1, S14.1, S14.4
unnamed: D56.C, R83.2
unnamed: D53.A, R79.1
unnamed: RPROG14.1, U29.5
unnamed: D57.C, TP15.P$1, U29.1
unnamed: L15.P$2, U30.1
unnamed: R86.1, R87.2, U30.5
unnamed: R88.2, U30.6
unnamed: J100.1, J101.2, J105.1, S15.1, S15.4
unnamed: D60.C, R89.2
unnamed: D57.A, R85.1
unnamed: RPROG15.1, U31.5
unnamed: D61.C, TP16.P$1, U31.1
unnamed: L16.P$2, U32.1
unnamed: R92.1, R93.2, U32.5
unnamed: R94.2, U32.6
unnamed: J107.1, J108.2, J112.1, S16.1, S16.4
unnamed: D64.C, R95.2
unnamed: D61.A, R91.1
unnamed: RPROG16.1, U33.5
unnamed: D65.C, TP17.P$1, U33.1
unnamed: L17.P$2, U34.1
unnamed: R98.1, R99.2, U34.5
unnamed: R100.2, U34.6
unnamed: J114.1, J115.2, J119.1, S17.1, S17.4
unnamed: D68.C, R101.2
unnamed: D65.A, R97.1
unnamed: RPROG17.1, U35.5
unnamed: D69.C, TP18.P$1, U35.1
unnamed: L18.P$2, U36.1
unnamed: R104.1, R105.2, U36.5
unnamed: R106.2, U36.6
unnamed: J121.1, J122.2, J126.1, S18.1, S18.4
unnamed: D72.C, R107.2
unnamed: D69.A, R103.1
unnamed: RPROG18.1, U37.5
unnamed: D73.C, TP19.P$1, U37.1
unnamed: L19.P$2, U38.1
unnamed: R110.1, R111.2, U38.5
unnamed: R112.2, U38.6
unnamed: J128.1, J129.2, J133.1, S19.1, S19.4
unnamed: D76.C, R113.2
unnamed: D73.A, R109.1
unnamed: RPROG19.1, U39.5
unnamed: D77.C, TP20.P$1, U39.1
unnamed: L20.P$2, U40.1
unnamed: R116.1, R117.2, U40.5
unnamed: R118.2, U40.6
unnamed: J135.1, J136.2, J140.1, S20.1, S20.4
unnamed: D80.C, R119.2
unnamed: D77.A, R115.1
unnamed: RPROG20.1, U41.5
unnamed: D81.C, TP21.P$1, U41.1
unnamed: L21.P$2, U42.1
unnamed: R122.1, R123.2, U42.5
unnamed: R124.2, U42.6
unnamed: J142.1, J143.2, J147.1, S21.1, S21.4
unnamed: D84.C, R125.2
unnamed: D81.A, R121.1
unnamed: RPROG21.1, U43.5
unnamed: D85.C, TP22.P$1, U43.1
unnamed: L22.P$2, U44.1
unnamed: R128.1, R129.2, U44.5
unnamed: R130.2, U44.6
unnamed: J149.1, J150.2, J154.1, S22.1, S22.4
unnamed: D88.C, R131.2
unnamed: D85.A, R127.1
unnamed: RPROG22.1, U45.5
unnamed: D89.C, TP23.P$1, U45.1
unnamed: L23.P$2, U46.1
unnamed: R134.1, R135.2, U46.5
unnamed: R136.2, U46.6
unnamed: J156.1, J157.2, J161.1, S23.1, S23.4
unnamed: D92.C, R137.2
unnamed: D89.A, R133.1
unnamed: RPROG23.1, U47.5
unnamed: D93.C, TP24.P$1, U47.1
unnamed: L24.P$2, U48.1
unnamed: R140.1, R141.2, U48.5
unnamed: R142.2, U48.6
unnamed: J163.1, J164.2, J168.1, S24.1, S24.4
unnamed: D96.C, R143.2
unnamed: D93.A, R139.1
unnamed: RPROG24.1, U49.5
unnamed: D97.C, TP25.P$1, U49.1
unnamed: L25.P$2, U50.1
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

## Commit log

2017-05-17 Created possible sparkfun product
    [Power_Cell_Lipo_Charger_Booster try2.brd, Power_Cell_Lipo_Charger_Booster try2.sch, Power_Cell_Lipo_Charger_Booster.brd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]
2017-07-10 Not sure why this wasn't pushed
    [Boost.brd, Boost.sch, ChargeBoost.brd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]
2017-07-19 Ready for review
    [Boost.brd, Boost.sch, LiPoChargerBooster5V1A.brd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]
2017-07-19 Added staking vias
    [LiPoChargerBooster5V1A.brd]
2017-07-20 Post reivew changes
    [LiPoChargerBooster5V1A.brd, LiPoChargerBooster5V1A.sch]
2017-07-24 Updated components and checked against the checklist, moved temp parts into normal eagle libs
    [LiPoChargerBooster5V1A.brd, LiPoChargerBooster5V1A.sch]
2017-07-31 Approved dimension DRC violations
    [LiPoChargerBooster5V1A.brd]
2017-09-21 Changed pull up to 750k, added photos
    [LiPoChargerBooster5V1A.brd, LiPoChargerBooster5V1A.sch, current offerings.ods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]
2017-09-29 Update README.md
    Re-add version history if there is ever a revision with the board.

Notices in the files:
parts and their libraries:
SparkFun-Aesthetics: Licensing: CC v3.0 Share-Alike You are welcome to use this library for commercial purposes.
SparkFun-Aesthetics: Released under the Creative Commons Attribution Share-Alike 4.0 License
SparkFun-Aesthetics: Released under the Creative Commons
